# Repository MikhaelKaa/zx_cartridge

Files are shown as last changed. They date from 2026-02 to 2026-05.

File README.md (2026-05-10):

# ZX Cartridge



Проект картриджа для компьютера **Дельта 128К**. Устройство реализовано на четырех 29040 и CPLD, подключается к слоту расширения компьютера. Репозиторий содержит полный набор как исходных файлов, так и файлы для производства.
Также есть схема в pdf. Есть две версии прошивки - для оригинальных картриджей и расширенный вариант.

На текущий момент (08.5.2026) собрано два экземпляра плат по герберам gerbers_22022026 - пока замечний нет.

## Функциональность

Проверена работа на дампах оригинальных картриджей - работает.

---

## Аппаратная часть (HW)

Печатная плата разработана в **Altium Designer** (файл `zx_cartridge.PrjPCB`).  
Структура папки `HW`:
- `zx_cartridge.PrjPCB` – проект.
- `src/` – исходные файлы схемы (`main.SchDoc`) и платы (`pcb.PcbDoc`).
- `altium_libs/` – библиотеки компонентов (субмодуль).  
  Библиотеки содержат посадочные места, условные обозначения и 3D-модели (папка `3dmodels` со STEP-файлами).  
  Репозиторий использует **git submodule** для подключения библиотек – это упрощает синхронизацию с обновлениями.

Изображения готового прототипа и модели платы можно найти в папке [`media`](#media).

---

## Программируемая часть (FW)

Прошивка для ПЛИС написана на Verilog и предназначена для синтеза в среде **Quartus** (файлы проекта `zx_cartridge.qpf`, `zx_cartridge.qsf`).  
Основной модуль – `zx_cartridge` (файл `src/zx_cartridge.v`).

Директория FW содержит расширенную версию прошивки, поддерживает до 2 мегабайт памяти (четыре 29040). В текушей версии прошивка помещается только в cpld с 64 ячеками.
[Полное описание логики работы](./FW/readme.md)

Директория FW_orig содержит версию прошивки для оригинальных картриджей дельты. Используется всего одна микросхема 29040 (DD1), дампы нужно склеить в один файл и залить с адреса 0x0. РОМы совместимые с этой прошивкой можно найти [тут](https://github.com/maximgorin79/d-cartridge128k/tree/main/roms).

## Медиа

В папке [`media`](media) находятся фотографии платы в процессе разработки прототипа.

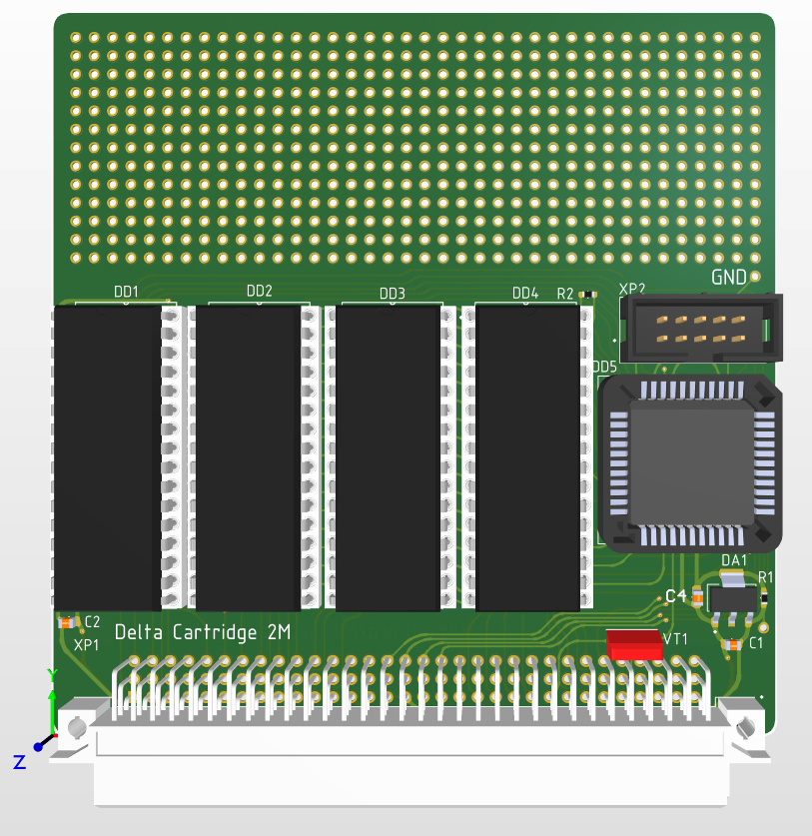
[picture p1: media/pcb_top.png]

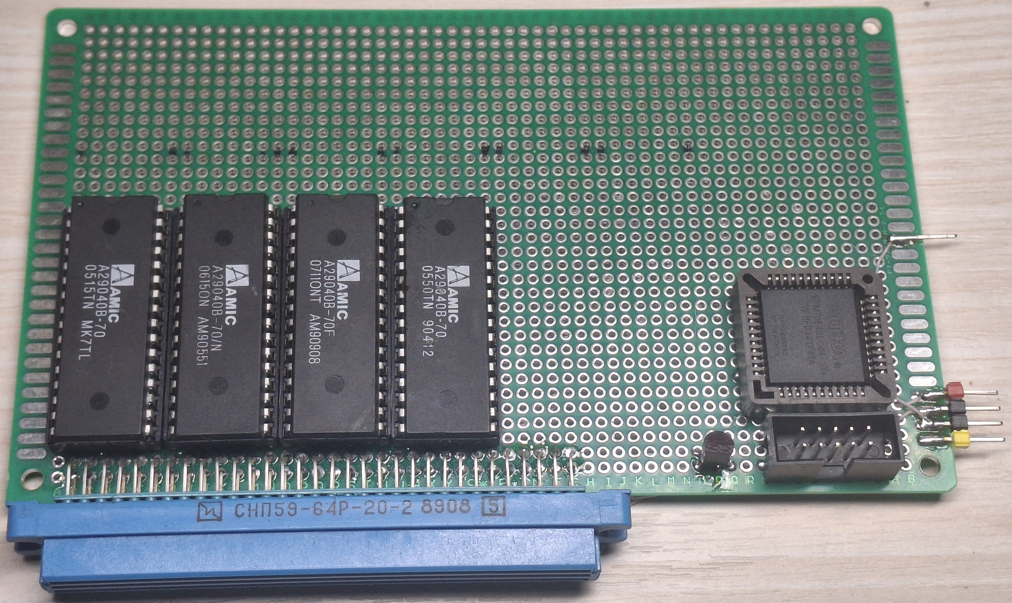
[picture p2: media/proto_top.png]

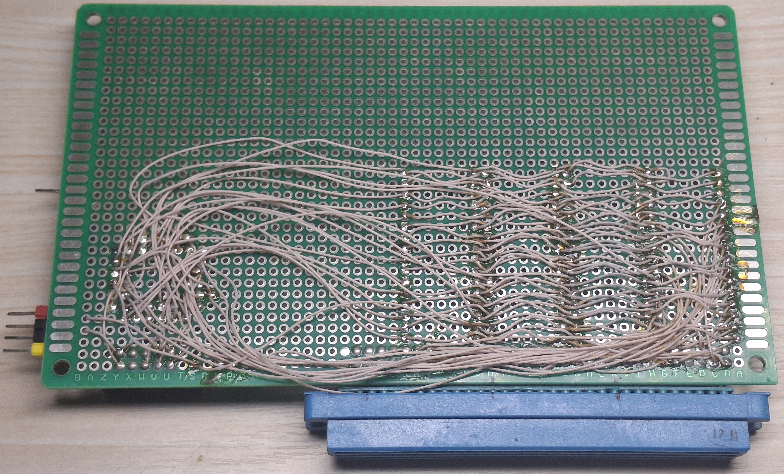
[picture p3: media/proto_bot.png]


## Благодарности

Спасибо за тест печатной платы @zcasper

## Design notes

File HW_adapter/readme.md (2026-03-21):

Переходник для поключения картриджа в BUS (ZS-Scorpion, например)

Схема сделана для монтажа на макетке, трассировка не предпологается.

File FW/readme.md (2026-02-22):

# ZX Spectrum Cartridge Controller — программисту

## Общая информация

Модуль `zx_cartridge` управляет четырьмя микросхемами ПЗУ типа AM29F040 (512 КБ каждая), что даёт **2 МБ** памяти.  
Память организована в виде **256 страниц по 8 КБ**. Страницы нумеруются от 0 до 255.

В адресном пространстве ZX Spectrum под картридж отведена область **0x0000…0x3FFF** (16 КБ, первые 16 КБ памяти).  
Эта область разделена на два 8‑КБ окна:

- **Нижнее окно** `0x0000…0x1FFF` (A13 = 0) — всегда **страница 0**.  
  Здесь должен располагаться код BIOS картриджа.

- **Верхнее окно** `0x2000…0x3FFF` (A13 = 1) — страница, номер которой задаётся программно через регистр `bank`.

## Регистры управления

Доступ к регистрам осуществляется через порты ввода‑вывода.  

### Порт `bank` (адрес **0xDF7F**)

- **Запись** (`OUT (0xDF7F), A`) — устанавливает номер страницы для верхнего окна.  
- **Чтение** (`IN A, (0xDF7F)`) — возвращает текущее значение регистра.

Формат байта `bank`:

| Биты 7–6 | Биты 5–0 |
|---|---|
| Выбор микросхемы (0–3) | Номер страницы внутри микросхемы (0–63) |

Таким образом, полный номер страницы = `(chip << 6) | page`.  
После сброса регистр равен 0 (микросхема 0, страница 0).

### Порт `control` (адрес **0xBF7F**)

- **Запись** (`OUT (0xBF7F), A`) — запись в управляющий регистр.  
- **Чтение** (`IN A, (0xBF7F)`) — чтение текущего значения.

Формат байта `control`:

| Биты 7 | Биты 6–0 |
|---|---|
| Отключение картриджа | Можно использовать по своему усмотрению |

- **Бит 7 = 0** — картридж включён (обычный режим).  
- **Бит 7 = 1** — картридж отключён. Выходы ПЗУ переводятся в высокоимпедансное состояние, внутреннее ПЗУ Spectrum работает штатно.

После сброса бит 7 = 0 (картридж включён).

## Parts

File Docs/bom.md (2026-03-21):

| Comment | Description | Designator | Footprint | LibRef | Quantity |
|---|---|---|---|---|---|
| 10uF | | C1, C2, C4, C5, C6 | C0805 | CapCer | 5 |
| AMS1117-3.3 | | DA1 | SOT229P700X180-4N | AMS1117-3.3 | 1 |
| AM29F040B | | DD1, DD2, DD3, DD4 | DIP254P1524X482-32 | AM29F040B | 4 |
| EPM7064SLC44 | 44-Pin PLCC44 | DD5 | PLCC-44-R | EPM7064SLC44 | 1 |
| 0 | | R1, R2 | R0603 | Res | 2 |
| КТ315Б | NPN Transistor | VT1 | KT-13 | КТ315Б | 1 |
| delta_device | | XP1 | DELTA-DEVICE | delta_device | 1 |
| BH-10 |  | XP2 | BH-10 | BH-10 | 1 |

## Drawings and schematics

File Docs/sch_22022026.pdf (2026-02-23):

# C2 10uF GND 123456789

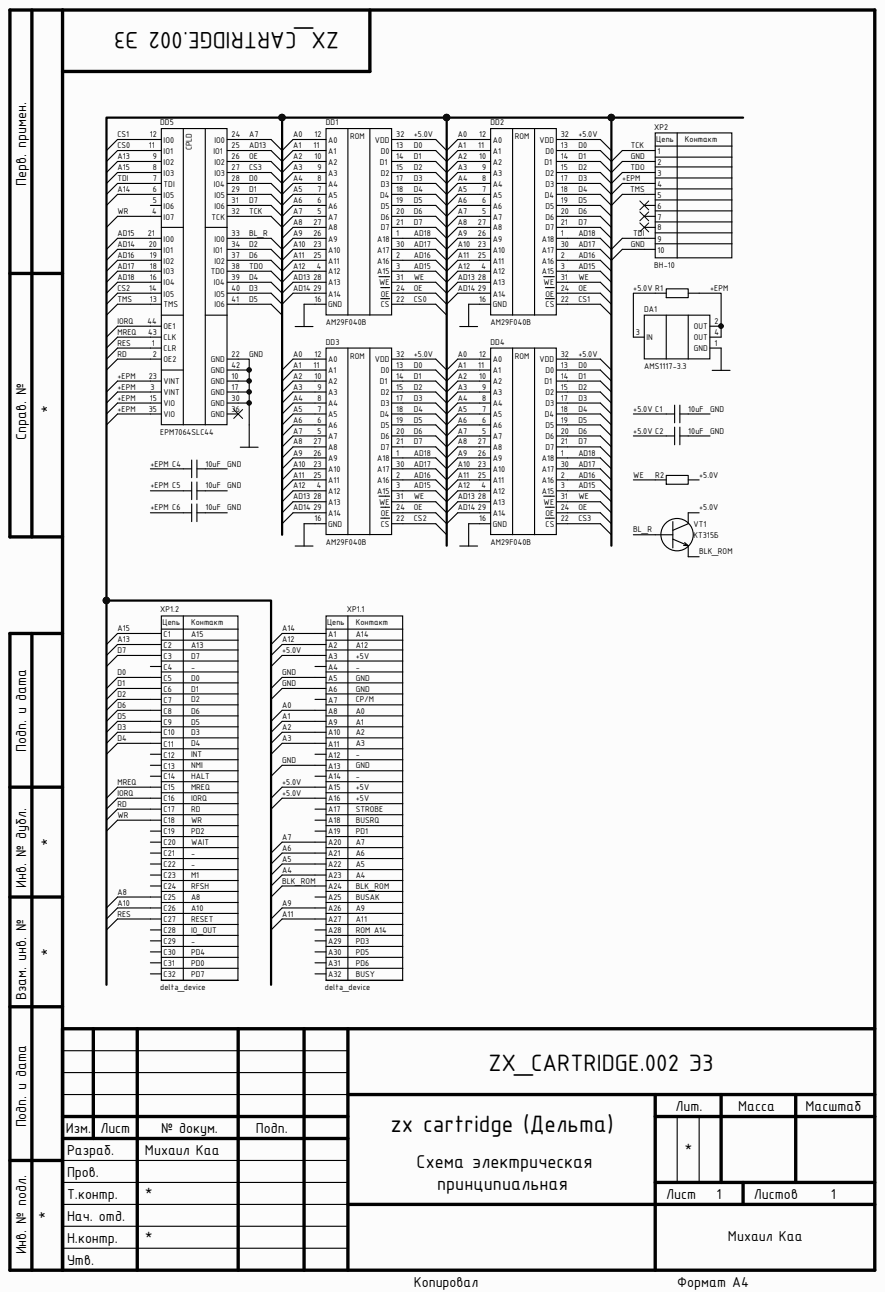
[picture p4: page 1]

Инв. № подл. Инв. № дубл. Подп. и дата Взам. инв. № Подп. и дата Перв. примен. Справ. №

ZX_CARTRIDGE.002 Э3

zx cartridge (Дельта) Схема электрическая принципиальная | Лит. | Масса | Масштаб

Изм. | Лист | № докум. | Подп. | | | *
Разраб. | | Михаил Каа
Пров.
Т.контр. | * | | | Лист 1 | Листов 1
Нач. отд.
Н.контр. | *
Утв.

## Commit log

2026-02-17 Its work!
    [pcb.PcbDoc]
2026-02-19 Версия совместимая с оригинальным картриджем.
    [main.SchDoc, pcb.PcbDoc]
2026-02-19 ext version batty start, but not work
    [main.SchDoc, pcb.PcbDoc]
2026-02-21 Примерная расстановка компонентов
    [main.SchDoc]
2026-02-21 Вариант трассировки 50%
    [main.SchDoc]
2026-02-22 Трассировка. На проверку
    [main.SchDoc, pcb.PcbDoc, zx_cartridge.PrjPCB]
2026-02-22 Version 22022026
    [pcb.PcbDoc]
2026-02-22 update pcb git text
    [pcb.PcbDoc]
2026-02-22 update sch pcb Незначительные изменения.
    [main.SchDoc, pcb.PcbDoc]
2026-02-23 PRE-RELEASE version
    [main.SchDoc, pcb.PcbDoc, zx_cartridge.PrjPCB]
2026-02-23 fix quartus pin assignment
    [zx_cartridge.PrjPCB]
2026-03-21 add PCB foto, BUS adapter prototype
    [main.SchDoc, pcb.PcbDoc, zx_cartridge_adapter.PrjPCB]
2026-03-21 delta adapter
    [pcb.PcbDoc]
2026-04-05 Add код для софтов оригинального картриджа.
2026-05-08 Отредактировать readme.md
    Добавлено описание прошивок.
2026-05-10 Добавить ссылку на репозитарий с ROM для оригинального картриджа.

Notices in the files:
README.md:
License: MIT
